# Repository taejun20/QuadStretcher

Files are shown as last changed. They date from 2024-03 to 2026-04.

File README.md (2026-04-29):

## QuadStretcher: A Forearm-Worn Skin Stretch Display for Bare-Hand Interaction in AR/VR (ACM CHI 2024)
<p align="center">
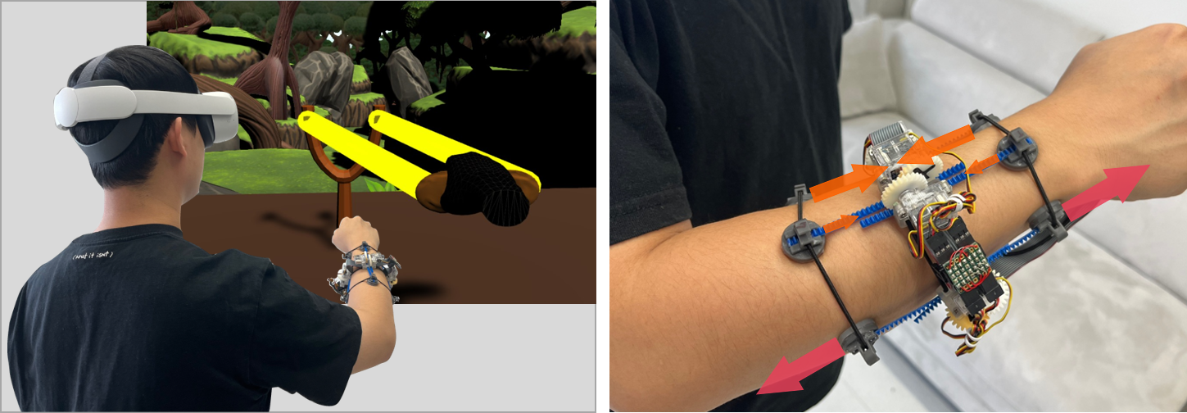
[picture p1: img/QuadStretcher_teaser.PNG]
    
</p>

-----------------

As bare-hand interaction has been rising in AR/VR environments, a crucial challenge emerges: How can we incorporate haptic feedback while keeping hands bare? **QuadStretcher** is a skin stretch display that delivers "substituted" haptic sensations on the forearm, facilitating immersive bare-hand AR/VR experiences. This work has been presented at [CHI 2024](https://chi2024.acm.org/), and more details about our work can be found in: [Paper](https://arxiv.org/pdf/2511.21157) | [DOI](https://dl.acm.org/doi/10.1145/3613904.3642067) | [Video](https://youtu.be/0LicmByEknI?si=bwrCasJZh_YbCokk)

<p align="center">
    
    <br>
    <sup> A use case example: QuadStretcher rendering real-time haptic feedback of the pulled rubber band.</sup>
</p>
<p align="center">
    
    <br>
    <sup> Four bare-hand interaction scenarios in VR: <b>Archery (Gradual Tension), Pistol (Impact), Sprayer (Rapid Tension), and Pulling Rubber Band (3-DoF Resistance Force)</b>.</sup>
</p>

## What does this repository contain?

This repository provides materials for reproducing our work:
* QuadStretcher Hardware ([Open Hardware: How To Make](openHardware/README.md))
  * 3D models (.stl) of servo motor housing, pinion gear, tactor, and magnet clip
  * Specifications and links to the used products: rack gear, magnet
  * Step-by-step guideline to build the QuadStretcher.  
* QuadStretcher Unity
  * Unity version: 2021.3.16f1
  * Running with VR Headset via [Meta Quest Link](https://www.meta.com/help/quest/articles/headsets-and-accessories/oculus-link/set-up-link/)
  * Four Unity Scenes (Archery, Pistol, Sprayer, and Slingshot) are ready.
* Used VR Headset
  * [Meta Quest 2](https://www.meta.com/kr/quest/products/quest-2/)

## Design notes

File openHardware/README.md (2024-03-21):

## Open Hardware: QuadStretcher (Page Working-in-Progress)

<p align="center">
    
</p>

<p> This page contains a step-by-step guideline to reproduce the artfiact, QuadStretcher.</p>

-----------------

## Stretching Module

* A stretching module has two counteracting tactors, and each tactor was driven by a servo motor via a rack-and-pinion mechanism.
  * 3D printed parts ([3D Printing Models](3D_Printing_Models_(.stl)/README.md))
    * Tactor
    * Servo Frame
    * Spur Gear
  * Commercial parts
    * Servo motor ([HiTec HS-40](https://www.hiteccs.com/actuators/product-details/HS-40))
    * Flexible Rack ([KHK DR0.8-2000](https://th.misumi-ec.com/en/vona2/detail/221004937839/?HissuCode=DR0.8-2000))
    * Silicon pad (3 mm thickness) - attached under the 3d-printed tactor

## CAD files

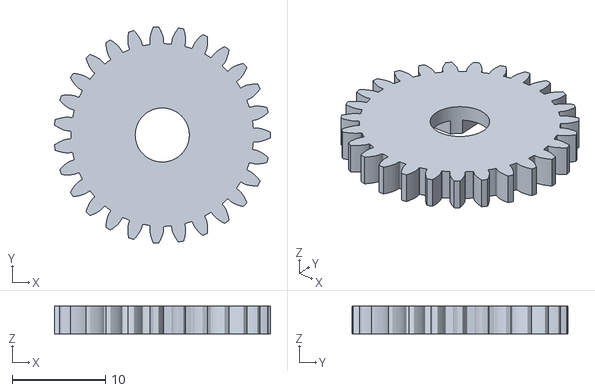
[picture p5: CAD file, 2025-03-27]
openHardware/3D_Printing_Models_(.stl)/spurGear.stl
23.2 x 23.2 x 3.00

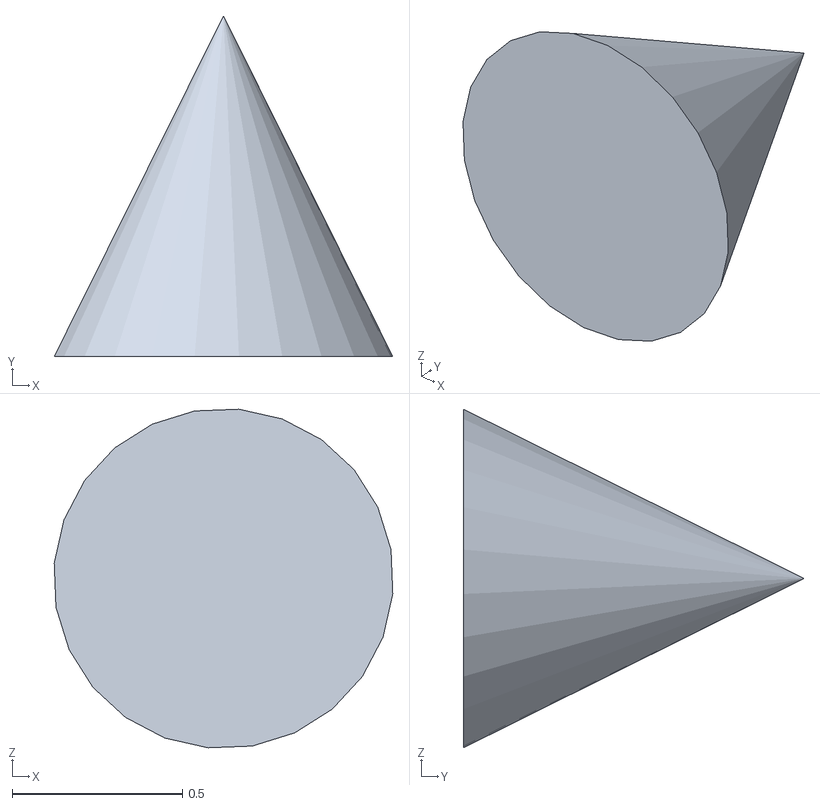
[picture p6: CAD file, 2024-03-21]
QuadStretcher Unity/Assets/Oculus/VR/Meshes/Cone.obj
0.996 x 1.00 x 0.996

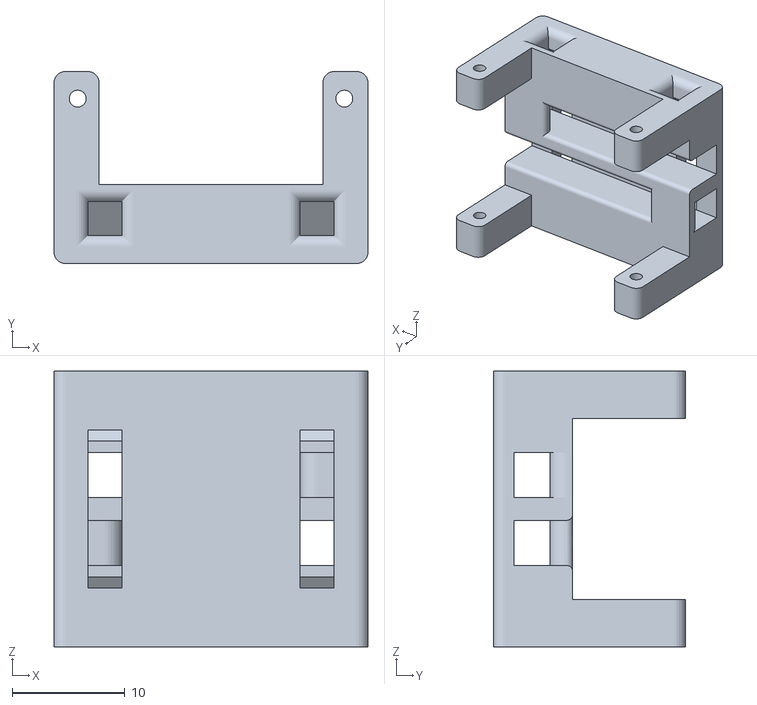
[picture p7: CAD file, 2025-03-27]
openHardware/3D_Printing_Models_(.stl)/servoFrame.stl
27.8 x 17.0 x 24.4

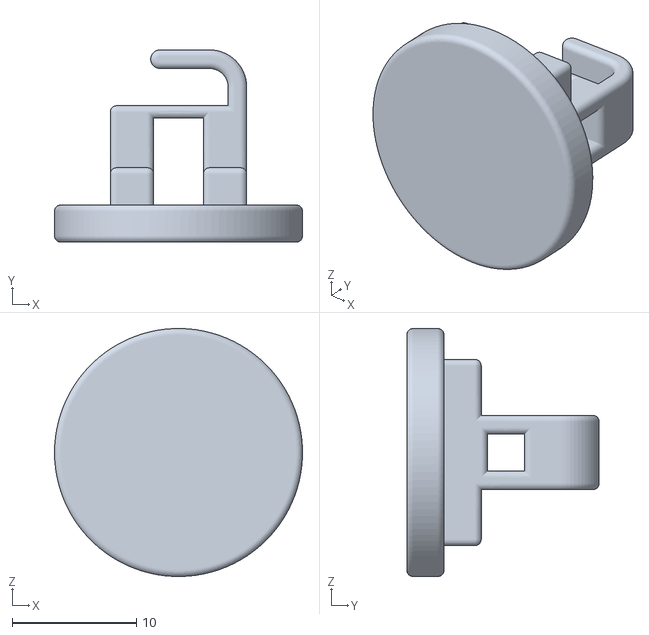
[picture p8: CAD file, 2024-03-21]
openHardware/3D_Printing_Models_(.stl)/tactor.stl
20.0 x 15.5 x 20.0

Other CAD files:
openHardware/3D_Printing_Models_(.stl)/Autodesk_Fusion_Project_Files_(.f3d)/servoFrameMaking.f3d
openHardware/3D_Printing_Models_(.stl)/Autodesk_Fusion_Project_Files_(.f3d)/spurGearMaking.f3d
openHardware/3D_Printing_Models_(.stl)/Autodesk_Fusion_Project_Files_(.f3d)/tactorMaking.f3d

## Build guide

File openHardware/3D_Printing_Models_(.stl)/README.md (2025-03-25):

## Autodesk Fusion: 3D modeling step-by-step 

Archival of the 3D modeling process on Autodesk Fusion.

## Spur Gear

<p align="center">
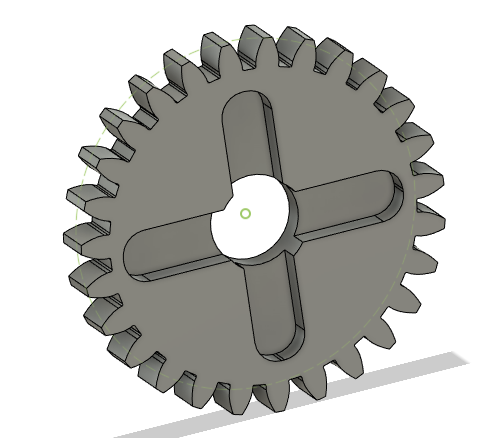
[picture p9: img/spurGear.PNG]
    
</p>

* On the top menu bar, Utilities - Add-INS - Scripts and Add-Ins
  
  
* On the bottom of the list, click SpurGear and Run
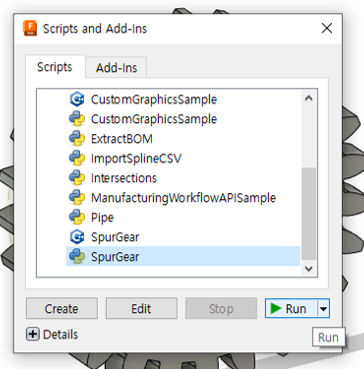
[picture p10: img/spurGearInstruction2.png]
  
  
* Set options and click OK.
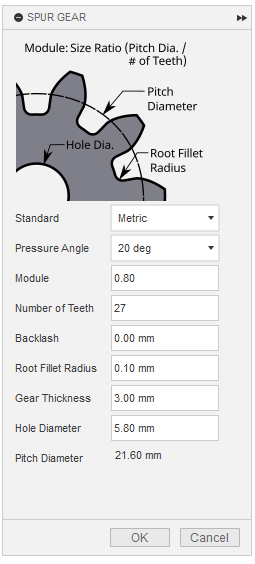
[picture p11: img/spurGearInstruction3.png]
  <p align="center"><br><sup>Pressure Angle: 20 deg, Module: 0.80, Number of Teeth: 27, Backlash: 0.00 mm, Root Fillet Radius: 0.10 mm, Gear Thickness: 3.00 mm, Hole Diameter: 5.80 mm (Pitch Diameter: 21.60 mm)</sup></p>
* Extruding
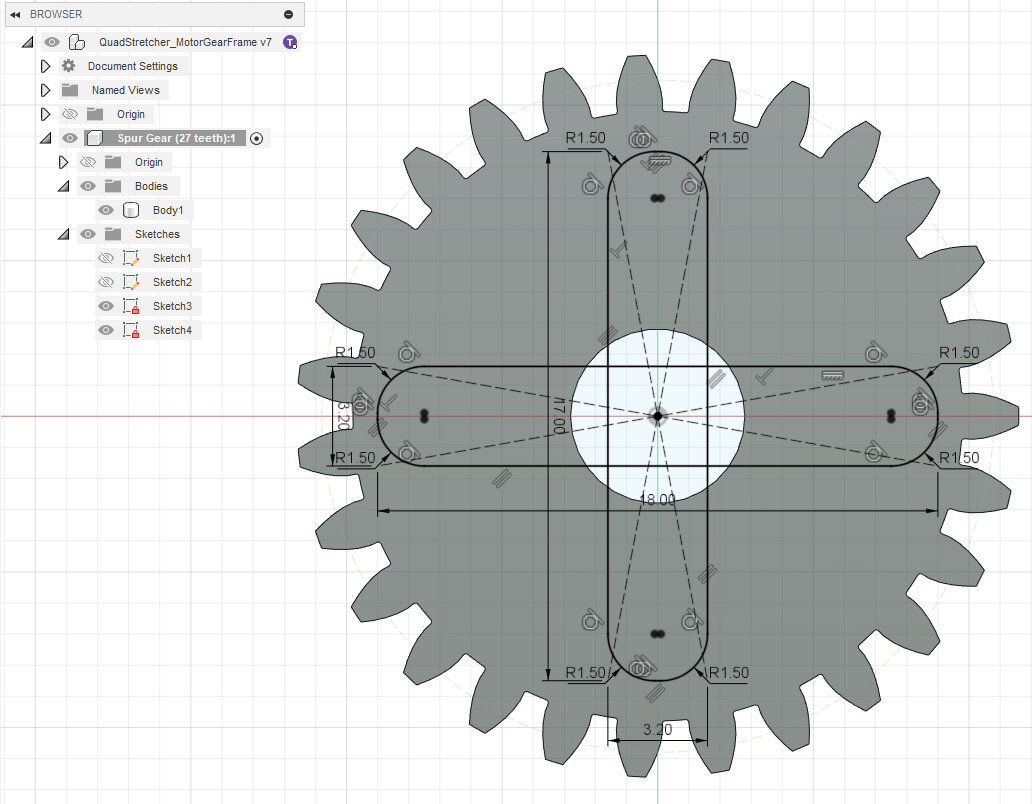
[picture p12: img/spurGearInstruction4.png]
  
  
  * Add a new sketch under the "Spur Gear" component in the hierarchy, (click activate component radio button on the right)
  * Draw the shapes using center rectangle and fillet on the four corners.
  * Extrude (depth: 1.50 mm)

## Servo Frame

<p align="center">
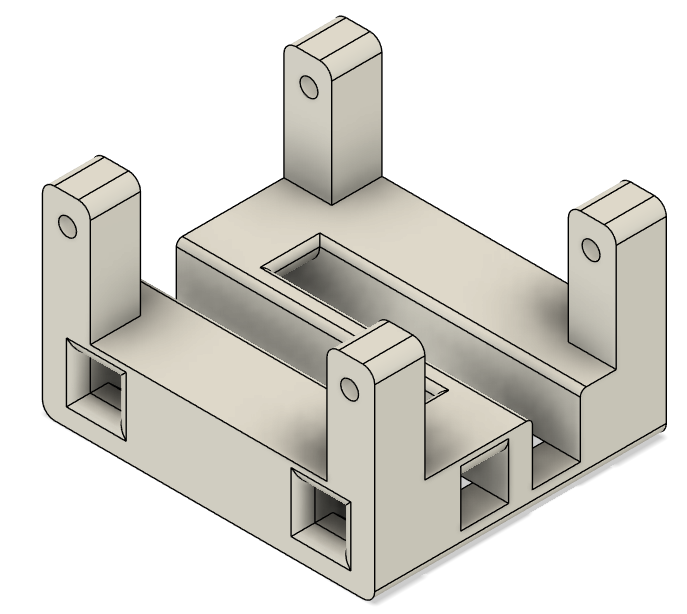
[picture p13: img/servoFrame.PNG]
    
</p>

* Please refer to the timeline history of the [servoFrameMaking.f3d](Autodesk_Fusion_Project_Files_(.f3d)/servoFrameMaking.f3d) for the modeling process.

## Tactor

<p align="center">
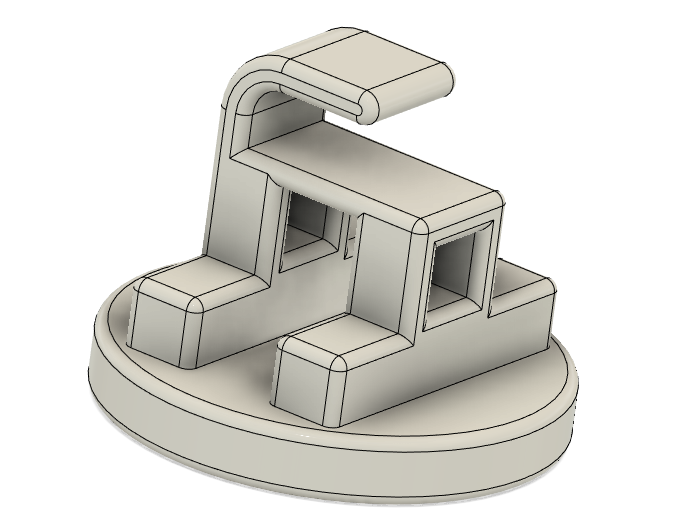
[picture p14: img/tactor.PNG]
    
</p>

* Please refer to the timeline history of the [tactorMaking.f3d](Autodesk_Fusion_Project_Files_(.f3d)/tactorMaking.f3d) for the modeling process (After printed, a silicon pad will be attached on the bottom).

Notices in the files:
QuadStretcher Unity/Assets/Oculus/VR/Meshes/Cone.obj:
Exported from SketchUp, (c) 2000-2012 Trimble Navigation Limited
